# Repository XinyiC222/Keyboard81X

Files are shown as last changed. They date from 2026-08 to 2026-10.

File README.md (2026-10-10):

# Keyboard81X WORK IN PROGRESS

A custom 75% PCB keyboard with a rotary encoder and 81 keys.

Screenshot 2026-08-02 at 5 42 08 PM







## Build Notes

- PCB was designed in **KiCad** using a keyswitch plugin.
  - If you are trying to find it here are the ones I used:
    - **KLE Placer**  /Organize the keys and diodes automatically based on .json file
    - **JLCPCB tools** / used for BOM and Placement for JLC pcbs (**EDIT**: New version does not use JLCPCB assembly so this tool was no longer used in the final version. But this tool really do come in handy!)
- Case was modeled in **Fusion**.
## Tools I used
- Plate was generated with: <http://builder.swillkb.com/>
- Keyboard Layout Editor: <https://www.keyboard-layout-editor.com/>
- Keycaps used in the model: <https://github.com/anhthang/dsa-keycap>
- Footprint Library I used in Kicad: <https://github.com/daprice/keyswitches.pretty>

## How To Build Your Own! <h3>PCB</h3>

1. Build your layout with the layout editor I mentioned in the tools I used.
2. Download the .json file from there.
3. In KiCad schematics choose your microcontroller or just use a chip. I used a **Raspberry Pi Pico** for the final version and placed it under the space bar. Other option: you could use a RP2040 chip and build somewhat of a dev board inside the project. That includes the Flash Memory to store the code, Crystal Oscillator (it's like the conductor), USB for power with a voltage regulator, and some capacitors.
4. Then add the current amount of MX_SW_HS you need based on the layout you made.
5. Add the same amount of diodes so each key has one that includes any rotary encoders.
6. Then after that you can add some MX_Stab for the ones you want to stabilize. Some keys like the spacebar need stabilizers, so you can change them to different footprints from the other keys. If you decided to use plate mounted stabilizers instead, you can leave this part out, otherwise if you're using pcb mounted stabilizers then you should add MX_Stab.
7. Add footprint to all your components and don't forget to **Annotate the entire Schematics**
8. Now when designing the PCB, using the .json file and the KLE Placer plugin, you can easily place them all accordingly.
9. Remember to add a border around to create the edge of the PCB in the Edge.cut layer.
10. Organize all the components to your liking and route all of them to each other.
11. **Generate the Gerber Files!**
12. Then if you were to use JLCPCB assembly, you can use the JLCPCB tools to find all the components and create the correct BOM and CPL.
13. You can then upload those files into JLCPCB and order from there!!

<h3>Case</h3>

1. Go into Fusion and create a new project.
2. Download the 3D view of your keyboard from KiCad and upload it (for reference!)
3. Then make the case around it any way you like. If you are 3D printing remember that prints can shrink so you need to **account for tolerances especially holes**
4. you can add a plate and any type of mounting you want
5. If you are adding a plate, the plate generator I included above might be helpful
6. For the plate if you are 3D printing with PLA, having it at 1.5mm thick is usually not strong enough. Set it to **3mm** but leave the area around the stabilizers to be 1.5mm. Note that **prioritizing stability would cause your switches to not clip on correctly**, but will still be tight enough to hold them.

<h3>That's pretty much a good summary of how to build your own keyboard! Thanks for reading it and I hope you learned something new. This is my first big project and definitely my first keyboard build so I don't expect everything to be correct. So if you are building this based off of mine, it's not guaranteed to work. Have fun!!</h3>

## Schematics
Screenshot 2026-09-01 at 12 31 02 PM

## PCB
Screenshot 2026-09-01 at 12 35 40 PM
Screenshot 2026-09-01 at 12 37 00 PM
Screenshot 2026-09-01 at 12 36 49 PM

## BOM
Everything under quantity is the amount you need but the links you buy them come in bulk so they give you more than what you need.

| Item | Purpose | Price | Quantity | Source |
| --- | --- | --- | --- | --- |
| Raspberry Pi Pico | Mirco-controller | $1.99 | 1 | [Aliexpress](https://www.aliexpress.com/item/3256807207612469.html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) |
| 1N5817 DO-41 | USB_C VBUS | $1.79 | x1 | [Aliexpress](https://www.aliexpress.com/item/3256809192784213.html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) |
| Keycaps | for the Keys | $4.73 | x80 | [Aliexpress](https://www.aliexpress.com/item/3256808108935624.html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) |
| Plate Mounted Stabilizers | stab for space bar etc | $2.99 | has one 6.25u and two 2u | [Aliexpress](https://www.aliexpress.com/item/3256808467378574.html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) |
| SMD turtle switches | Reset button | $2.19 | x1 | [Aliexpress](https://www.aliexpress.com/item/3256805092773328.html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) |
| Hot Swap Sockets | hot swap keys | $6.20 | x80 | [Aliexpress](https://www.aliexpress.com/item/3256809001206372.html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) |
| Silent Axis switch | switches | $7.66 | x80 | [Aliexpress](https://www.aliexpress.com/item/3256812192263951.html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) |
| Type C Female | PCB for power | $2.24 | x1 | [Aliexpress](https://www.aliexpress.com/item/3256804989275660.html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) |
| Solder | soldering | $2.14 | x1 | [Aliexpress](https://www.aliexpress.com/item/3256812349220377.html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) |
| 5.1k resistors | for ground near usb-c | $2.48 | x2 | [Aliexpress](https://www.aliexpress.com/item/3256811592848349.html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) |
| IN4148 DO-35 | matrix | $1.92 | x81 | [Aliexpress](https://www.aliexpress.com/item/3256809322506944.html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) |
| Heat Inserts | To mount plate | $0.00 | 2 | Already Owned |
| M2.5 x 15mm bolts | Mount plate | $0.00 | 2 | Already Owned |
| Rotary Encoder | Volume knob | $0.00 | 1 | Already Owned |
| PCB | Connects everything | $39.36 | 1 | JLCPCB |
| 3D Prints | case for all the parts | $0.00 | | Printing Legion |
| Sub-Total+Tax |  | $37.48 |  | Aliexpress |
| Total |  | $76.84 |  | All Combined |

## Credits
<div align="center">
  



</div>

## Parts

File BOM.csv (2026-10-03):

Item | Purpose | Price | Quantity | Source | URL
Raspberry Pi Pico | Mirco-controller | $1.99 | 1 | Aliexpress | https://www.aliexpress.com/item/3256807207612469.html?mp=1&sourceType=570
1N5817 DO-41 | USB_C VBUS | $1.79 | x1 | Aliexpress | https://www.aliexpress.com/item/3256809192784213.html?mp=1
Keycaps | for the Keys | $4.73 | x80 | Aliexpress | https://www.aliexpress.com/item/3256808108935624.html?mp=1
Plate Mounted Stabilizers | stab for space bar etc | $2.99 | has one 6.25u and two 2u | Aliexpress | https://www.aliexpress.com/item/3256808467378574.html?mp=1&sourceType=570
SMD turtle switches | Reset button | $2.19 | x1 | Aliexpress | https://www.aliexpress.com/item/3256805092773328.html?mp=1&sourceType=570
Hot Swap Sockets | hot swap keys | $6.20 | x80 | Aliexpress | https://www.aliexpress.com/item/3256809001206372.html?mp=1
Silent Axis switch | switches | $7.66 | x80 | Aliexpress | https://www.aliexpress.com/item/3256812192263951.html?mp=1
Type C Female | PCB for power | $2.24 | x1 | Aliexpress | https://www.aliexpress.com/item/3256804989275660.html?mp=1
Solder | soldering | $2.14 | x1 | Aliexpress | https://www.aliexpress.com/item/3256812349220377.html?mp=1
5.1k resistors | for ground near usb-c | $2.48 | x2 | Aliexpress | https://www.aliexpress.com/item/3256811592848349.html?mp=1
IN4148 DO-31 | matrix | $1.92 | x81 | Aliexpress | https://www.aliexpress.com/item/3256809322506944.html?mp=1&sourceType=570
Heat Inserts | To mount plate | $0.00 | 2 | Already Owned
M2.5 x 15mm bolts | Mount plate | $0.00 | 2 | Already Owned
Rotary Encoder | Volume knob | $0.00 | 1 | Already Owned
PCB | Connects everything | $39.36 | 1 | JLCPCB | https://jlcpcb.com/
3D Prints | case for all the parts | $0.00 |  | Printing Legion
Sub-Total+Tax |  | $37.48 |  | Aliexpress
Total |  | $76.84 |  | All Combined

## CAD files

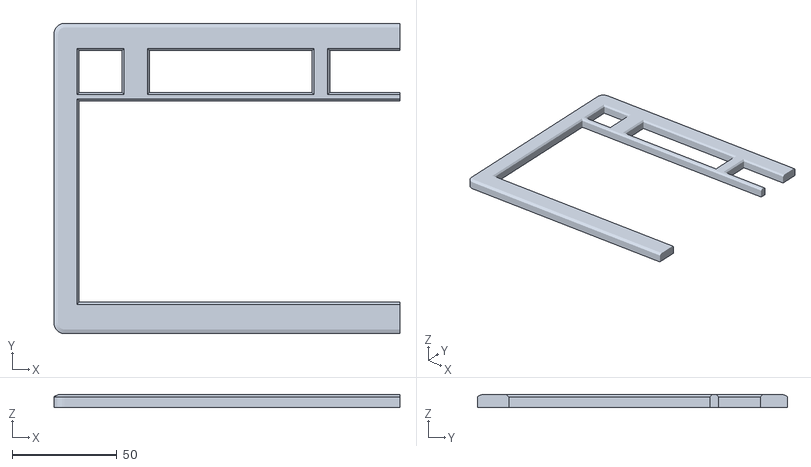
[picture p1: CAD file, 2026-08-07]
Print Files/Case/TopL.stl
165.0 x 148.0 x 6.00

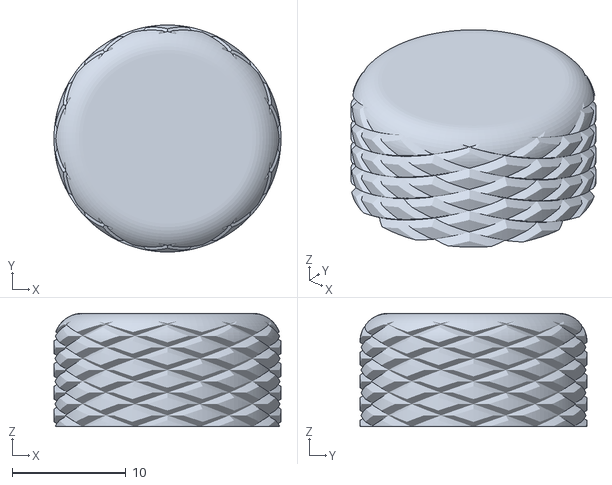
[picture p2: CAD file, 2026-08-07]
Print Files/Knob.stl
20.0 x 20.0 x 10.0

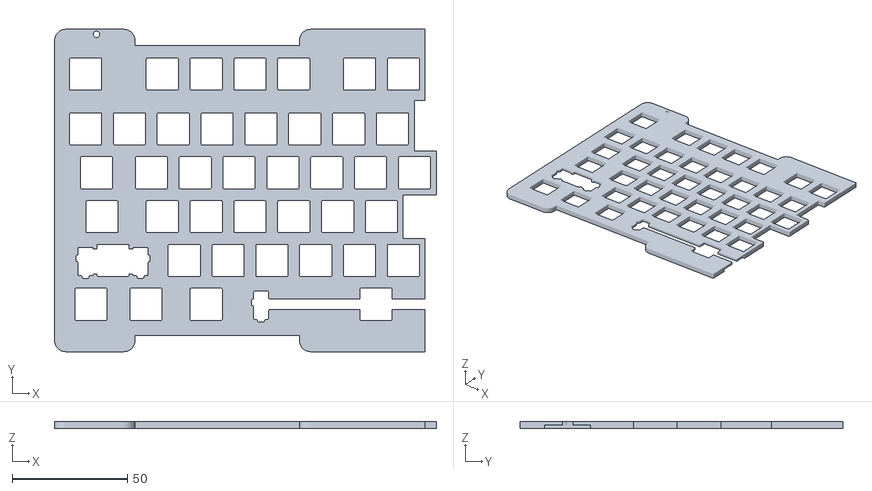
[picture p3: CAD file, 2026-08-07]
Print Files/Plate/PlateL.stl
166.0 x 140.2 x 3.00

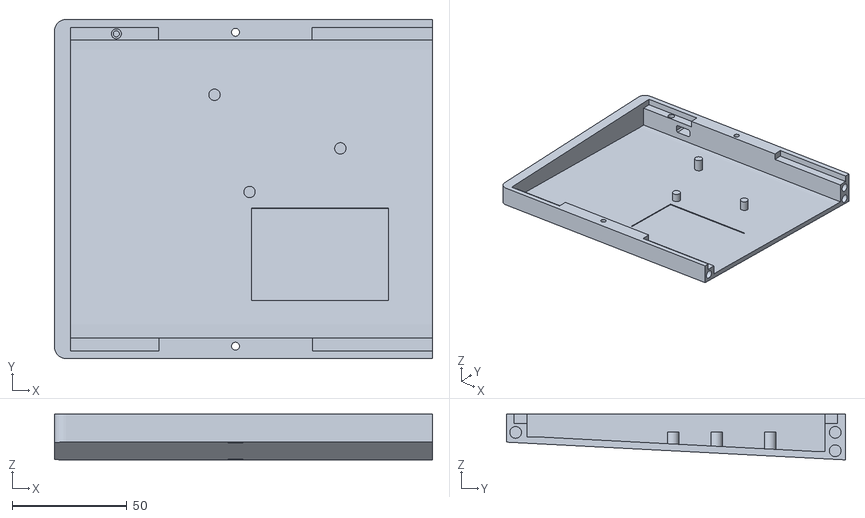
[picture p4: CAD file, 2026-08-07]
Print Files/Case/BottomL.stl
165.0 x 148.0 x 20.0

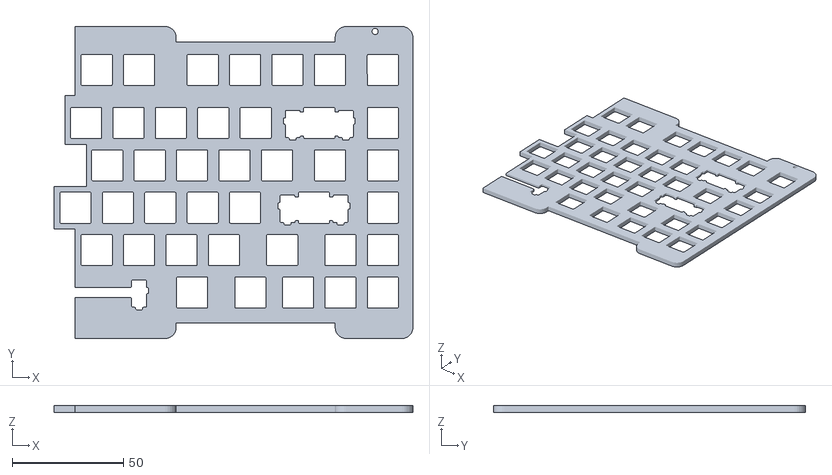
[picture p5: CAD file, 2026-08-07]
Print Files/Plate/PlateR.stl
161.3 x 140.2 x 3.00

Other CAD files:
Project Files/Fusion/Knob.step
Project Files/Fusion/PlateL.step
Print Files/Case/BottomR.stl
Project Files/Fusion/PlateR.step
Print Files/Case/TopR.stl
Project Files/Fusion/TopL.step
Project Files/Fusion/BottomL.step
Project Files/Fusion/BottomR.step
Project Files/Fusion/TopR.step
Project Files/Fusion/Case.f3d
Project Files/Fusion/Knob.f3d
Project Files/Fusion/Plate.f3d

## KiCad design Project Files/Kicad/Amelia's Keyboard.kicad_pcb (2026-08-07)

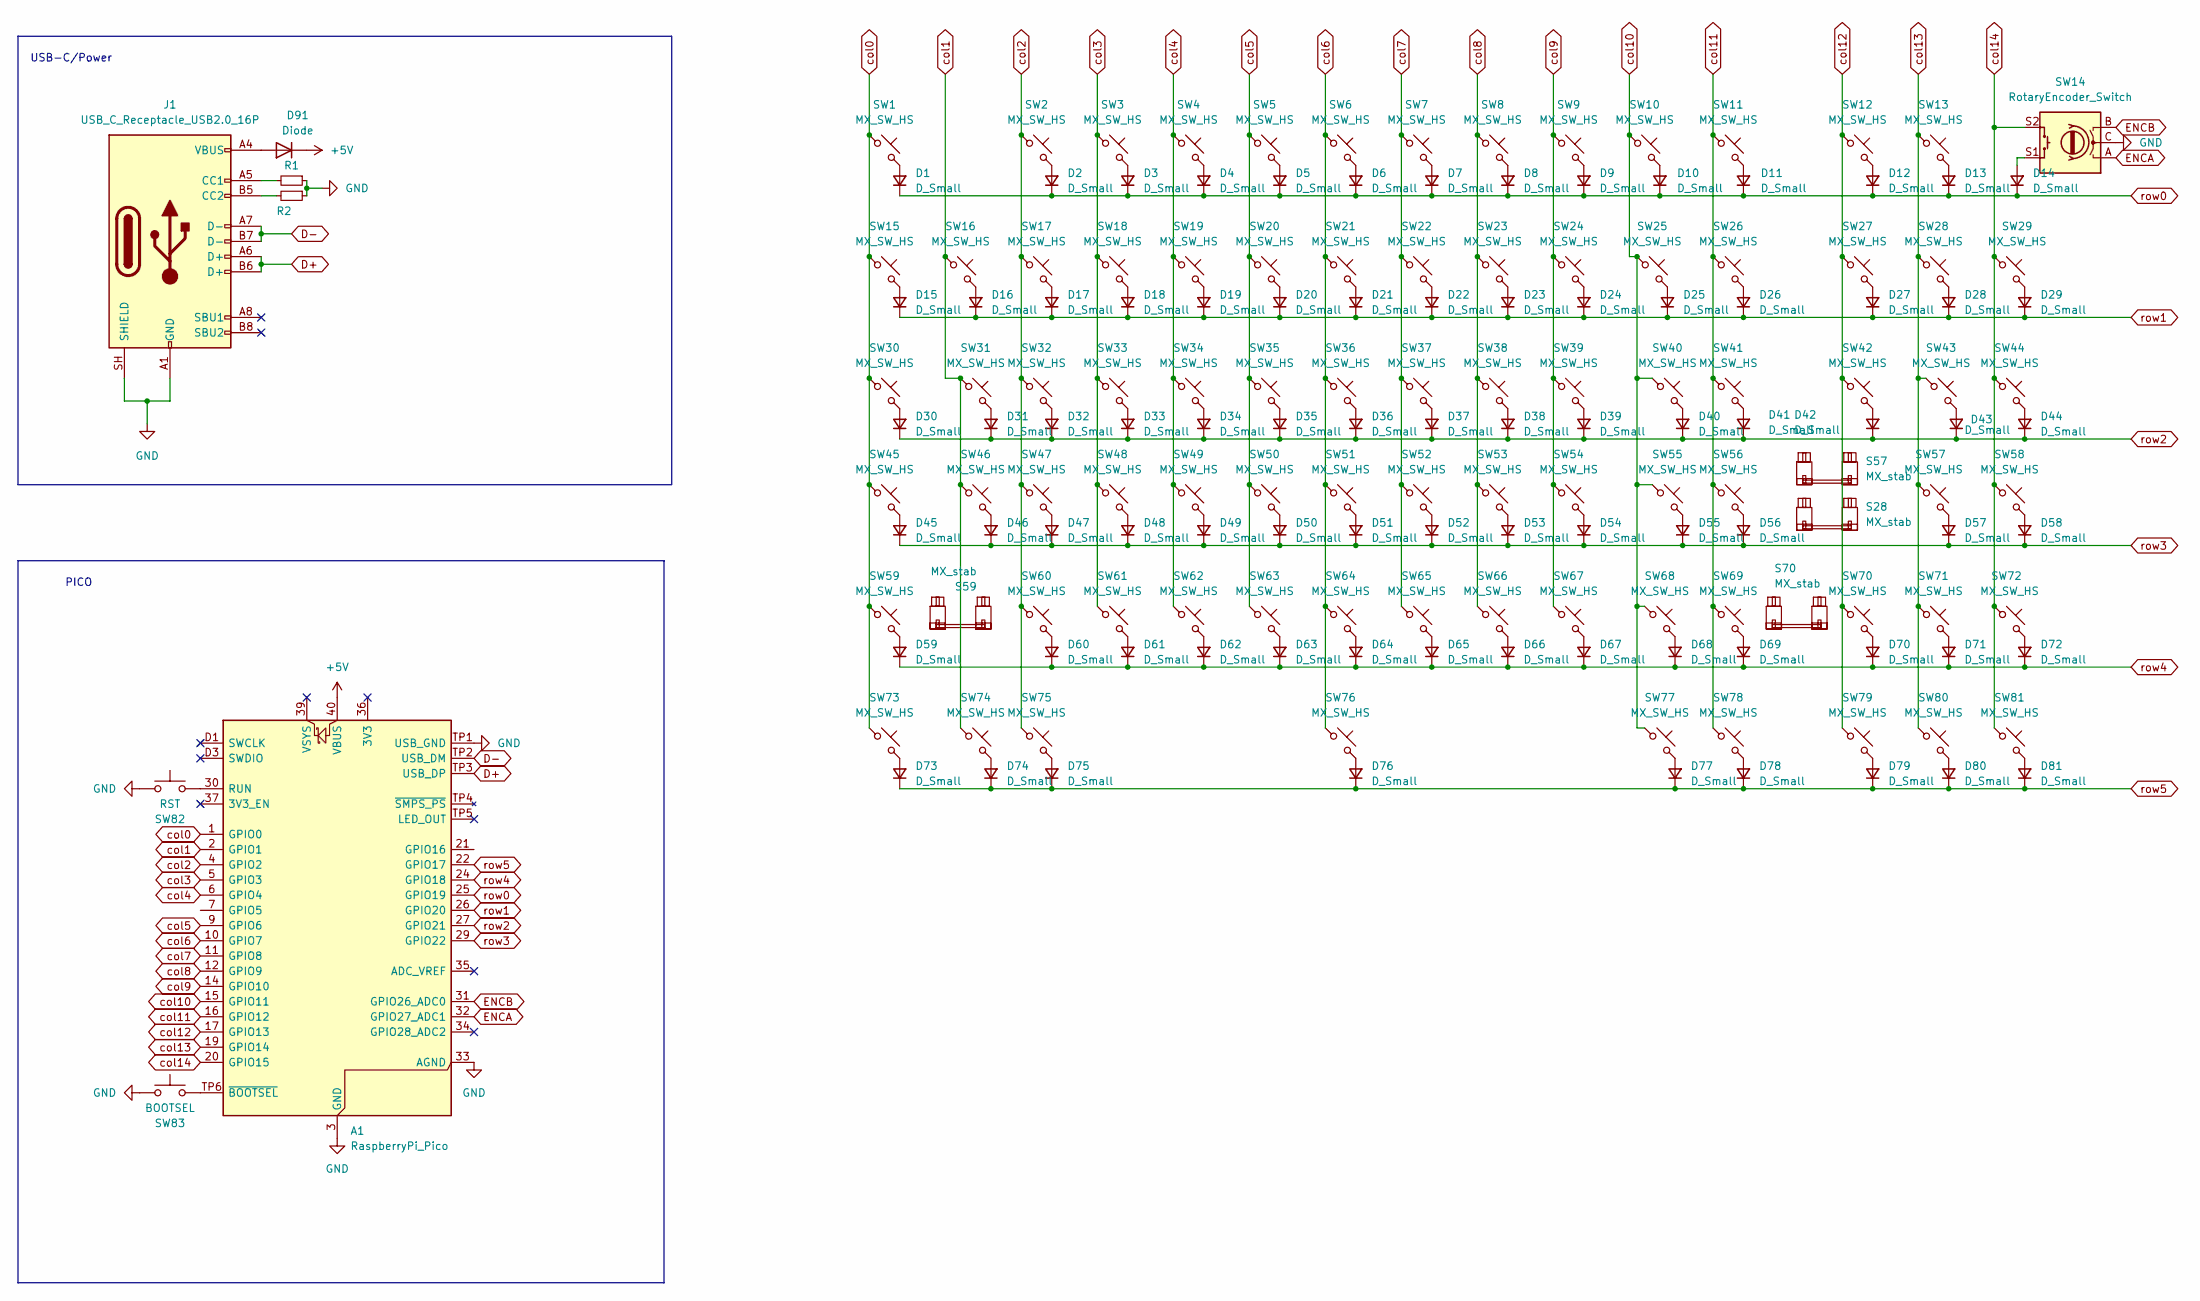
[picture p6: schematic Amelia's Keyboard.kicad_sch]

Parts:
A1: RaspberryPi_Pico; RaspberryPi_Pico_SMD
D1, D2, D3, D4, D5, D6, D7, D8, D9, D10, D11, D12, D13, D14, D15, D16, D17, D18, D19, D20, D21, D22, D23, D24, D25, D26, D27, D28, D29, D30, D31, D32, D33, D34, D35, D36, D37, D38, D39, D40, D41, D42, D43, D44, D45, D46, D47, D48, D49, D50, D51, D52, D53, D54, D55, D56, D57, D58, D59, D60, D61, D62, D63, D64, D65, D66, D67, D68, D69, D70, D71, D72, D73, D74, D75, D76, D77, D78, D79, D80, D81: D_Small; Diode_DO-35
D91: Diode; D_DO-41_SOD81_P7.62mm_Horizontal
J1: USB_C_Receptacle_USB2.0_16P; USB_C_Receptacle_HCTL_HC-TYPE-C-16P-01A
R1: R1; R_0805_2012Metric_Pad1.20x1.40mm_HandSolder
R2: R2; R_0805_2012Metric_Pad1.20x1.40mm_HandSolder
S28, S70: MX_stab; STAB_MX_P_2u
S57, S59: MX_stab; STAB_MX_P_2.25u
SW1, SW2, SW3, SW4, SW5, SW6, SW7, SW8, SW9, SW10, SW11, SW12, SW13, SW15, SW16, SW17, SW18, SW19, SW20, SW21, SW22, SW23, SW24, SW25, SW26, SW27, SW29, SW31, SW32, SW33, SW34, SW35, SW36, SW37, SW38, SW39, SW40, SW41, SW42, SW44, SW46, SW47, SW48, SW49, SW50, SW51, SW52, SW53, SW54, SW55, SW56, SW58, SW60, SW61, SW62, SW63, SW64, SW65, SW66, SW67, SW68, SW69, SW71, SW72, SW79, SW80, SW81: MX_SW_HS; SW_MX_HS_CPG151101S11_1u
SW14: RotaryEncoder_Switch; Encoder_EC11_MX
SW28, SW57: MX_SW_HS; SW_Hotswap_Kailh_MX_2.00u
SW30, SW43, SW75, SW77: MX_SW_HS; SW_MX_HS_CPG151101S11_1.5u
SW45, SW70: MX_SW_HS; SW_MX_HS_CPG151101S11_1.75u
SW59: MX_SW_HS; SW_Hotswap_Kailh_MX_2.25u
SW73, SW74, SW78: MX_SW_HS; SW_MX_HS_CPG151101S11_1.25u
SW76: MX_SW_HS; SW_Hotswap_Kailh_MX_6.25u
SW82: RST; SW_SPST_TS-1088-xR025
SW83: BOOTSEL; SW_SPST_TS-1088-xR025

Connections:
+5V: A1.40 (VBUS), D91.1 (K)
D+: A1.TP3 (USB_DP), J1.A6 (D+), J1.B6 (D+)
D-: A1.TP2 (USB_DM), J1.A7 (D-), J1.B7 (D-)
ENCA: A1.32 (GPIO27_ADC1), SW14.A
ENCB: A1.31 (GPIO26_ADC0), SW14.B
GND: A1.3 (GND), A1.8 (GND), A1.13 (GND), A1.18 (GND), A1.23 (GND), A1.28 (GND), A1.33 (AGND), A1.38 (GND), A1.D2 (GND), A1.TP1 (USB_GND), J1.A1 (GND), J1.A12 (GND), J1.B1 (GND), J1.B12 (GND), J1.SH (SHIELD), R1.1, R2.1, SW14.C, SW82.1, SW83.1
unnamed: A1.30 (RUN), SW82.2
unnamed: A1.TP6 (~BOOTSEL), SW83.2
unnamed: D1.2 (A), SW1.2
unnamed: D2.2 (A), SW2.2
unnamed: D3.2 (A), SW3.2
unnamed: D4.2 (A), SW4.2
unnamed: D5.2 (A), SW5.2
unnamed: D6.2 (A), SW6.2
unnamed: D7.2 (A), SW7.2
unnamed: D8.2 (A), SW8.2
unnamed: D9.2 (A), SW9.2
unnamed: D10.2 (A), SW10.2
unnamed: D11.2 (A), SW11.2
unnamed: D12.2 (A), SW12.2
unnamed: D13.2 (A), SW13.2
unnamed: D14.2 (A), SW14.S1
unnamed: D15.2 (A), SW15.2
unnamed: D16.2 (A), SW16.2
unnamed: D17.2 (A), SW17.2
unnamed: D18.2 (A), SW18.2
unnamed: D19.2 (A), SW19.2
unnamed: D20.2 (A), SW20.2
unnamed: D21.2 (A), SW21.2
unnamed: D22.2 (A), SW22.2
unnamed: D23.2 (A), SW23.2
unnamed: D24.2 (A), SW24.2
unnamed: D25.2 (A), SW25.2
unnamed: D26.2 (A), SW26.2
unnamed: D27.2 (A), SW27.2
unnamed: D28.2 (A), SW28.2
unnamed: D29.2 (A), SW29.2
unnamed: D30.2 (A), SW30.2
unnamed: D31.2 (A), SW31.2
unnamed: D32.2 (A), SW32.2
unnamed: D33.2 (A), SW33.2
unnamed: D34.2 (A), SW34.2
unnamed: D35.2 (A), SW35.2
unnamed: D36.2 (A), SW36.2
unnamed: D37.2 (A), SW37.2
unnamed: D38.2 (A), SW38.2
unnamed: D39.2 (A), SW39.2
unnamed: D40.2 (A), SW40.2
unnamed: D41.2 (A), SW41.2
unnamed: D42.2 (A), SW42.2
unnamed: D43.2 (A), SW43.2
unnamed: D44.2 (A), SW44.2
unnamed: D45.2 (A), SW45.2
unnamed: D46.2 (A), SW46.2
unnamed: D47.2 (A), SW47.2
unnamed: D48.2 (A), SW48.2
unnamed: D49.2 (A), SW49.2
unnamed: D50.2 (A), SW50.2
unnamed: D51.2 (A), SW51.2
unnamed: D52.2 (A), SW52.2
unnamed: D53.2 (A), SW53.2
unnamed: D54.2 (A), SW54.2
unnamed: D55.2 (A), SW55.2
unnamed: D56.2 (A), SW56.2
unnamed: D57.2 (A), SW57.2
unnamed: D58.2 (A), SW58.2
unnamed: D59.2 (A), SW59.2
unnamed: D60.2 (A), SW60.2
unnamed: D61.2 (A), SW61.2
unnamed: D62.2 (A), SW62.2
unnamed: D63.2 (A), SW63.2
unnamed: D64.2 (A), SW64.2
unnamed: D65.2 (A), SW65.2
unnamed: D66.2 (A), SW66.2
unnamed: D67.2 (A), SW67.2
unnamed: D68.2 (A), SW68.2
unnamed: D69.2 (A), SW69.2
unnamed: D70.2 (A), SW70.2
unnamed: D71.2 (A), SW71.2
unnamed: D72.2 (A), SW72.2
unnamed: D73.2 (A), SW73.2
unnamed: D74.2 (A), SW74.2
unnamed: D75.2 (A), SW75.2
unnamed: D76.2 (A), SW76.2
unnamed: D77.2 (A), SW77.2
unnamed: D78.2 (A), SW78.2
unnamed: D79.2 (A), SW79.2
unnamed: D80.2 (A), SW80.2
unnamed: D81.2 (A), SW81.2
unnamed: D91.2 (A), J1.A4 (VBUS), J1.A9 (VBUS), J1.B4 (VBUS), J1.B9 (VBUS)
unnamed: J1.A5 (CC1), R1.2
unnamed: J1.B5 (CC2), R2.2
col0: A1.1 (GPIO0), SW1.1, SW15.1, SW30.1, SW45.1, SW59.1, SW73.1
col1: A1.2 (GPIO1), SW16.1, SW31.1, SW46.1, SW74.1
col2: A1.4 (GPIO2), SW2.1, SW17.1, SW32.1, SW47.1, SW60.1, SW75.1
col3: A1.5 (GPIO3), SW3.1, SW18.1, SW33.1, SW48.1, SW61.1
col4: A1.6 (GPIO4), SW4.1, SW19.1, SW34.1, SW49.1, SW62.1
col5: A1.9 (GPIO6), SW5.1, SW20.1, SW35.1, SW50.1, SW63.1
col6: A1.10 (GPIO7), SW6.1, SW21.1, SW36.1, SW51.1, SW64.1, SW76.1
col7: A1.11 (GPIO8), SW7.1, SW22.1, SW37.1, SW52.1, SW65.1
col8: A1.12 (GPIO9), SW8.1, SW23.1, SW38.1, SW53.1, SW66.1
col9: A1.14 (GPIO10), SW9.1, SW24.1, SW39.1, SW54.1, SW67.1
col10: A1.15 (GPIO11), SW10.1, SW25.1, SW40.1, SW55.1, SW68.1, SW77.1
col11: A1.16 (GPIO12), SW11.1, SW26.1, SW41.1, SW56.1, SW69.1, SW78.1
col12: A1.17 (GPIO13), SW12.1, SW27.1, SW42.1, SW70.1, SW79.1
col13: A1.19 (GPIO14), SW13.1, SW28.1, SW43.1, SW57.1, SW71.1, SW80.1
col14: A1.20 (GPIO15), SW14.S2, SW29.1, SW44.1, SW58.1, SW72.1, SW81.1
row0: A1.25 (GPIO19), D1.1 (K), D2.1 (K), D3.1 (K), D4.1 (K), D5.1 (K), D6.1 (K), D7.1 (K), D8.1 (K), D9.1 (K), D10.1 (K), D11.1 (K), D12.1 (K), D13.1 (K), D14.1 (K)
row1: A1.26 (GPIO20), D15.1 (K), D16.1 (K), D17.1 (K), D18.1 (K), D19.1 (K), D20.1 (K), D21.1 (K), D22.1 (K), D23.1 (K), D24.1 (K), D25.1 (K), D26.1 (K), D27.1 (K), D28.1 (K), D29.1 (K)
row2: A1.27 (GPIO21), D30.1 (K), D31.1 (K), D32.1 (K), D33.1 (K), D34.1 (K), D35.1 (K), D36.1 (K), D37.1 (K), D38.1 (K), D39.1 (K), D40.1 (K), D41.1 (K), D42.1 (K), D43.1 (K), D44.1 (K)
row3: A1.29 (GPIO22), D45.1 (K), D46.1 (K), D47.1 (K), D48.1 (K), D49.1 (K), D50.1 (K), D51.1 (K), D52.1 (K), D53.1 (K), D54.1 (K), D55.1 (K), D56.1 (K), D57.1 (K), D58.1 (K)
row4: A1.24 (GPIO18), D59.1 (K), D60.1 (K), D61.1 (K), D62.1 (K), D63.1 (K), D64.1 (K), D65.1 (K), D66.1 (K), D67.1 (K), D68.1 (K), D69.1 (K), D70.1 (K), D71.1 (K), D72.1 (K)
row5: A1.22 (GPIO17), D73.1 (K), D74.1 (K), D75.1 (K), D76.1 (K), D77.1 (K), D78.1 (K), D79.1 (K), D80.1 (K), D81.1 (K)

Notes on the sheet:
USB-C/Power
PICO

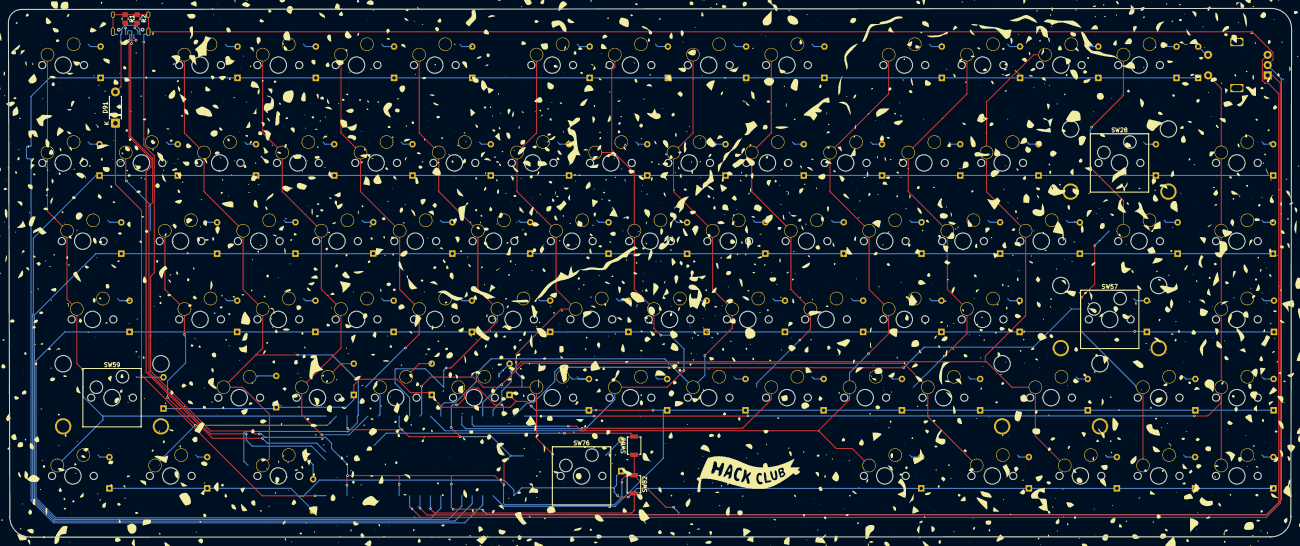
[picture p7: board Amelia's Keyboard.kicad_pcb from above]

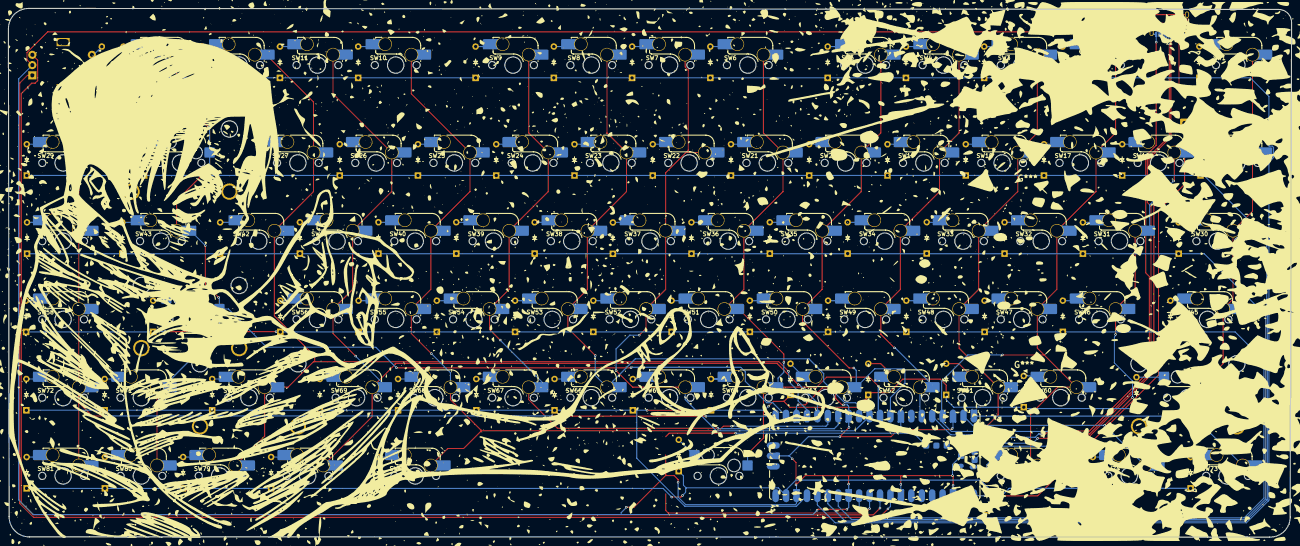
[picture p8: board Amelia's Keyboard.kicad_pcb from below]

Board: 2 copper layers, 312.4 x 128.7 mm, 173 parts (163 on the bottom side), 113 nets.

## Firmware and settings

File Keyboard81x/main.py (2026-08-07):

import board
from kmk.kmk_keyboard import KMKKeyboard
from kmk.keys import KC
from kmk.scanners import DiodeOrientation
from kmk.modules.encoder import EncoderHandler
from kmk.extensions.media_keys import MediaKeys
from kmk.extensions.mouse_keys import MouseKeys

keyboard = KMKKeyboard()
keyboard.extensions.append(MouseKeys())


keyboard.col_pins = (
    board.GP0, board.GP1, board.GP2, board.GP3, board.GP4,
    board.GP6, board.GP7, board.GP8, board.GP9, board.GP10,
    board.GP11, board.GP12, board.GP13, board.GP14, board.GP15
)

keyboard.row_pins = (
    board.GP19,
    board.GP20,
    board.GP21,
    board.GP22,
    board.GP18,
    board.GP17,
)

keyboard.diode_orientation = DiodeOrientation.COL2ROW

media_keys = MediaKeys()
ecoder_handler = EncoderHandler()

keyboard.modules.append(encoder_handler)
keyboard.extensions.append(MediaKeys())
keyboard.extensions.append(MouseKeys())

encoder_handler.pins = (
    (board.GP27, board.GP26, None, False), #ENCA ENCB SW is_inverted
)

encoder_handler.map = [
    ((KC.VOLD, KC.VOLU),),
]

Base = 0
FN = 1

_ = KC.TRNS

# ┌───┐ ┌───┬───┬───┬───┐ ┌───┬───┬───┬───┐ ┌───┬───┬───┬───┐ ┌───┐
# │Esc│ │Bri│Bru│ F3│Fnd│ │Wak│Slp│Prv│Ply│ │Nxt│Mut│Vol│Vol│ │ROT│
# └───┘ └───┴───┴───┴───┘ └───┴───┴───┴───┘ └───┴───┴───┴───┘ └───┘
# ┌───┬───┬───┬───┬───┬───┬───┬───┬───┬───┬───┬───┬───┬───────┬───┐
# │ ~ │ 1 │ 2 │ 3 │ 4 │ 5 │ 6 │ 7 │ 8 │ 9 │ 0 │ - │ = │Backsp │Fnd│
# ├───┴─┬─┴─┬─┴─┬─┴─┬─┴─┬─┴─┬─┴─┬─┴─┬─┴─┬─┴─┬─┴─┬─┴─┬─┴─┬─────┼───┤
# │ Tab │ Q │ W │ E │ R │ T │ Y │ U │ I │ O │ P │ [ │ ] │  \  │Und│
# ├─────┴┬──┴┬──┴┬──┴┬──┴┬──┴┬──┴┬──┴┬──┴┬──┴┬──┴┬──┴┬──┴─────┼───┤
# │ Caps │ A │ S │ D │ F │ G │ H │ J │ K │ L │ ; │ ' │ Enter  │Pst│
# ├──────┴─┬─┴─┬─┴─┬─┴─┬─┴─┬─┴─┬─┴─┬─┴─┬─┴─┬─┴─┬─┴─┬─┴────┬───┼───┤
# │ Shift  │ Z │ X │ C │ V │ B │ N │ M │ , │ . │ / │Shift │ ↑ │Cpy│
# ├────┬───┴┬──┴─┬─┴───┴───┴───┴───┴───┴──┬┴───┴┬──┴──┬───┼───┼───┤
# │Ctrl│Alt │Cmd │         Space          │RGu  │Alt  │ ← │ ↓ │ → │
# └────┴────┴────┴────────────────────────┴─────┴─────┴───┴───┴───┘

keyboard.keymap = [
    [
    #row 0
    KC.ESC, KC.BRID, KC.BRIU, KC.F3, KC.FIND,
    KC.WAKE, KC.SLEP, KC.MPRV, KC.MPLY, KC.MNXT,
    KC.MUTE, KC.VOLD, KC.VOLU,

    #row 1
    KC.GRV, KC.N1, KC.N2, KC.N3, KC.N4,
    KC.N5, KC.N6, KC.N7, KC.N8, KC.N9,
    KC.N0, KC.MINS, KC.EQL, KC.BSPC, KC.DEL,

    #row 2
    KC.TAB, KC.Q, KC.W, KC.E, KC.R,
    KC.T, KC.Y, KC.U, KC.I, KC.O,
    KC.P, KC.LBRC, KC.RBRC, KC.BSLS, KC.MS_WH_UP,

    #row 3
    KC.CAPS, KC.A, KC.S, KC.D, KC.F,
    KC.G, KC.H, KC.J, KC.K, KC.L,
    KC.SCLN, KC.QUOT, KC.ENT, KC.MS_WH_DOWN,

    #row 4
    KC.LSFT, KC.Z, KC.X, KC.C, KC.V,
    KC.B, KC.N, KC.M, KC.COMM, KC.DOT,
    KC.SLSH, KC.RSFT, KC.UP, KC.END,

    #row
    KC.LCTL, KC.LALT, KC.LGUI, KC.SPC, KC.RGUI, KC.RALT, KC.LEFT, KC.DOWN, KC.RGHT,

    ],
]

if __name__ == '__main__':
    keyboard.go()

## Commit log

2026-07-13 Rename Amelia's Keyboard.kicad_pcb to Project Files/Kicad/Amelia's Keyboard.kicad_pcb
    [Amelia's Keyboard.kicad_pcb]
2026-07-13 Rename Print Files/BottomR.3mf to Print Files/Case/BottomR.3mf
    [BottomR.3mf]
2026-07-13 Rename Print Files/PlateL.3mf to Print Files/Plate/PlateL.3mf
    [PlateL.3mf]
2026-08-04 Add Bill of Materials with item details
    Added BOM details including items, purposes, prices, quantities, and sources.
    [BOM.csv]
2026-08-07 Updated Case files
    [BottomL.step, BottomR.step, TopL.step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]
2026-08-07 new plates
    [PlateL.step, PlateR.step]
2026-08-07 Knob print files
    [Knob.step]
2026-08-07 New project files
    [Knob.f3d]
2026-08-07 New print files moved .step to project
    [BottomL.step, BottomL.stl, BottomR.step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]
2026-08-07 Add solder entry to BOM.csv
    [BOM.csv]
2026-08-07 Update BOM section with detailed components list
    Added detailed BOM with item descriptions, prices, quantities, and sources.
2026-08-07 Modify BOM.csv with updated prices and totals
    Updated prices for keycaps and PCB, and added subtotal and total calculations.
    [BOM.csv]
2026-09-01 Update BOM.csv with revised quantities and items
    [BOM.csv]
2026-09-01 Update quantity for 1N5817 and 5.1k resistors
    [BOM.csv]
2026-09-30 Fix PCB quantity from 'need 1' to '1'
    [BOM.csv]
2026-10-03 Add URLs to BOM.csv for all components
    [BOM.csv]
2026-10-03 Update BOM.csv to add missing items and fix formatting
    [BOM.csv]
